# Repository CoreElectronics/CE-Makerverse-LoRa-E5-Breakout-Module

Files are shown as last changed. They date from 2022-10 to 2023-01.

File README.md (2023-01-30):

# Makerverse™ LoRa-E5 Breakout

This is the repo for the [Makerverse™ LoRa-E5 Breakout](https://core-electronics.com.au/catalog/product/view/sku/CE09196).

## License
This project is open source - please review the LICENSE.md file for further licensing information.

If you have any technical questions, or concerns about licensing, please contact technical support on the [Core Electronics forums](https://forum.core-electronics.com.au/).

## Attribution
The hardware design of this module is influenced by the [Wio-E5 mini](https://wiki.seeedstudio.com/LoRa_E5_mini/).

*\"Makerverse\" and the Makerverse logo are trademarks of Core Electronics Pty Ltd.*

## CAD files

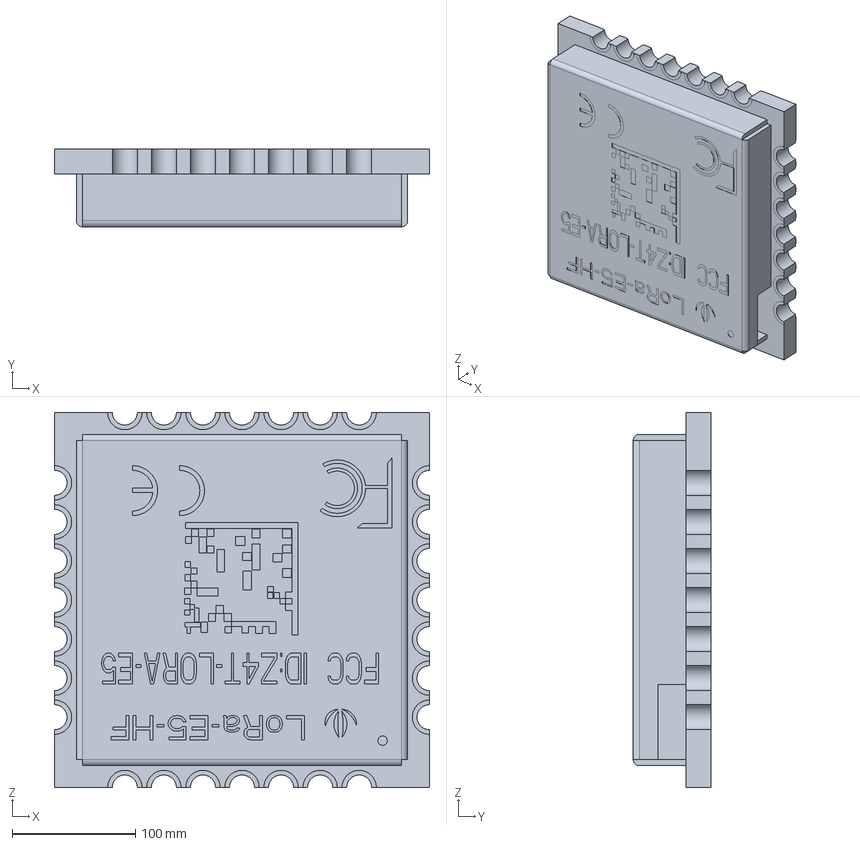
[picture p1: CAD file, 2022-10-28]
CAD/LoRa-E5-HF_3D_File.stp
304.8 x 63.8 x 304.8 mm

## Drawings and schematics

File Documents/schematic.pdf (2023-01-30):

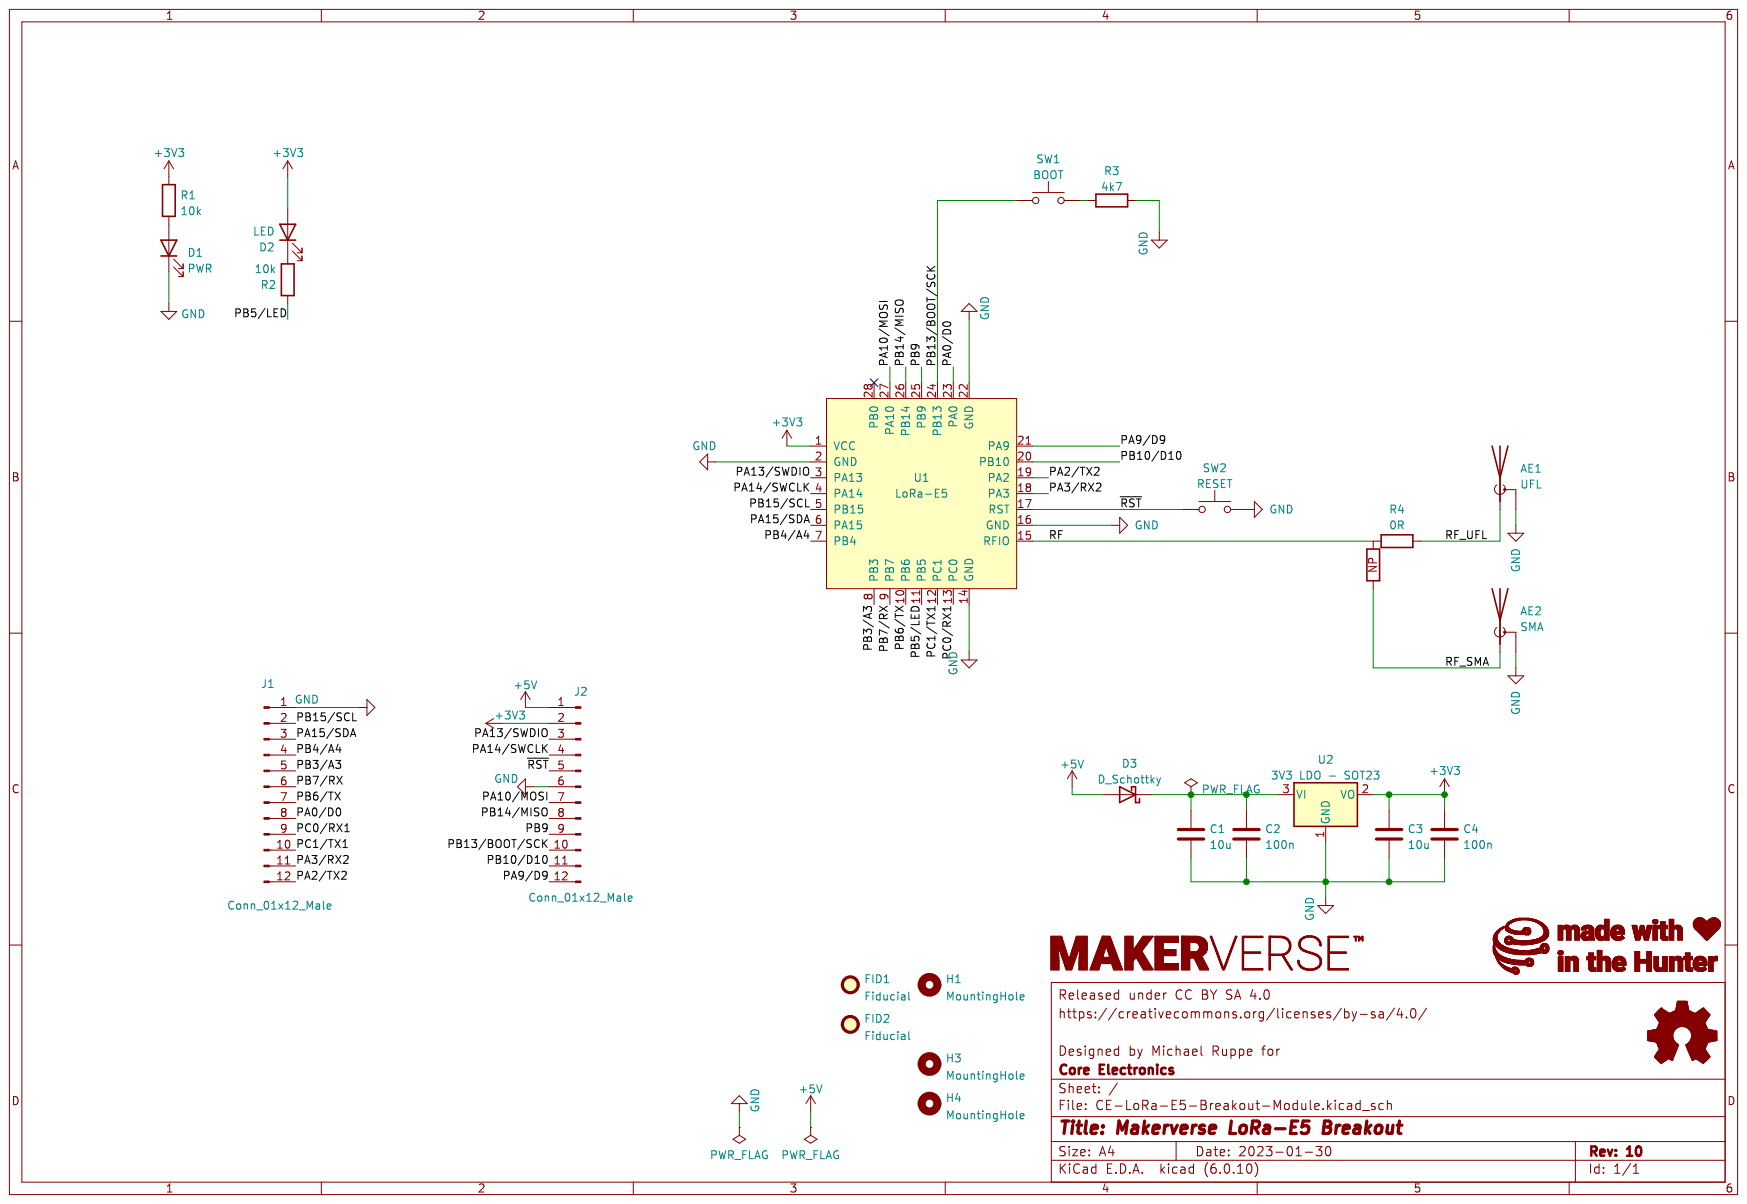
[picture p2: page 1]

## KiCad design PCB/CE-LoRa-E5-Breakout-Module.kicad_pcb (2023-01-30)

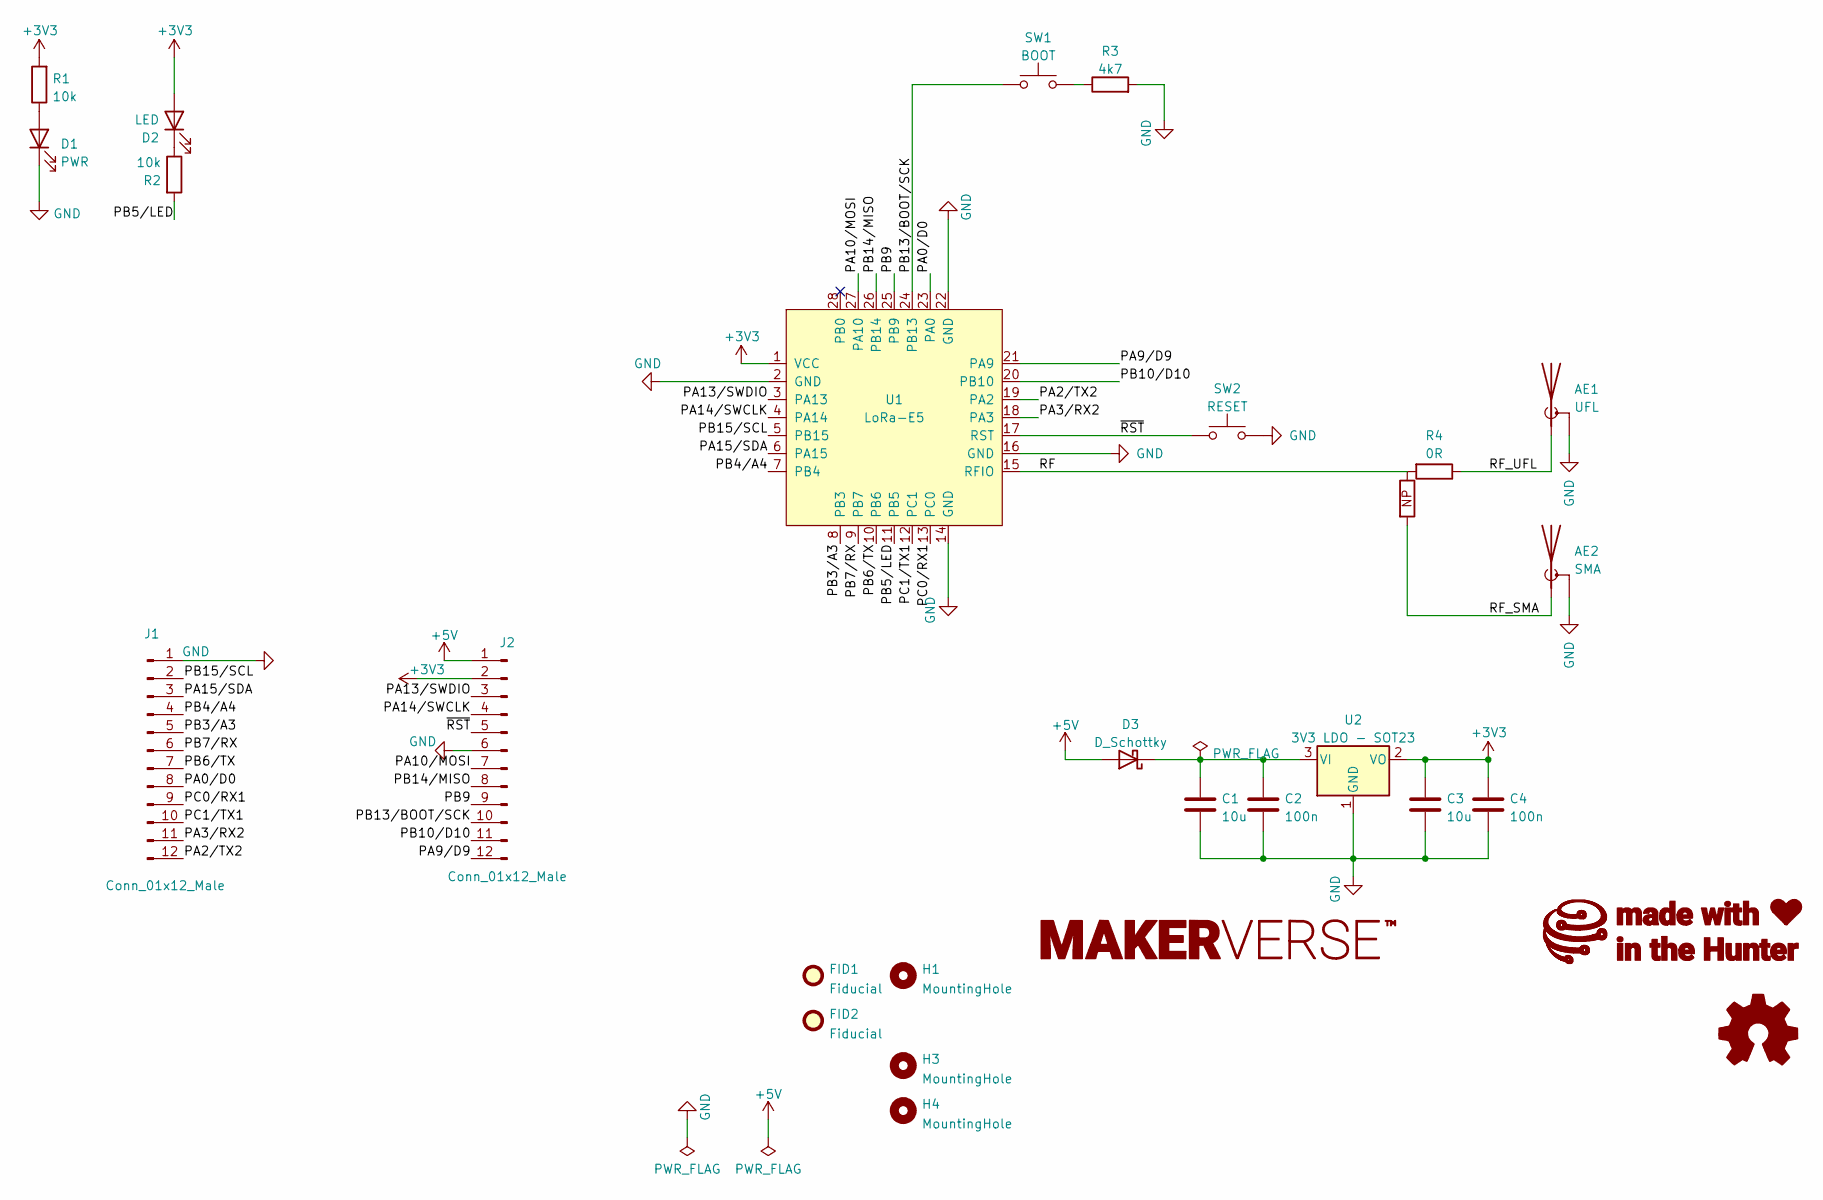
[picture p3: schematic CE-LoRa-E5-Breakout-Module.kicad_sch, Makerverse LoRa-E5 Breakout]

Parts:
AE1: UFL; U.FL_Hirose_U.FL-R-SMT-1_Vertical
AE2: SMA; Conn_RF_SMA_EdgeMount
C1, C3: 10u; C_0603_1608Metric
C2, C4: 100n; C_0402_1005Metric
D1: PWR; LED_0603_1608Metric
D2: LED; LED_0603_1608Metric
D3: D_Schottky; D_SMA
FID1, FID2: Fiducial; Fiducial_1mm_Mask2mm
G1: LOGO_Makerverse; makerverse_logo_short_14.0x2.4mm
G2: LOGO_CoreElectronics_made-with-love; makerverse_logo_35.8x4.2mm
H1, H3, H4: MountingHole; MountingHole_3.2mm_M3
J1, J2: Conn_01x12_Male; PinHeader_1x12_P2.54mm_Vertical
LOGO1: Logo_Open_Hardware_Small; oshw_3.9x3.5mm
R1, R2: 10k; R_0402_1005Metric
R3: 4k7; R_0402_1005Metric
R4: 0R; Jumper_Resistor_SPDT_0603_1608Metric
SW1: BOOT; SW_SPST_TL3342
SW2: RESET; SW_SPST_TL3342
U1: LoRa-E5
U2: 3V3 LDO - SOT23; SOT-23

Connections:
+3V3: C3.1, C4.1, D2.2 (A), J2.2, R1.2, U1.1 (VCC), U2.2 (VO)
+5V: D3.2 (A), J2.1
/PA0/D0: J1.8, U1.23 (PA0)
/PA2/TX2: J1.12, U1.19 (PA2)
/PA3/RX2: J1.11, U1.18 (PA3)
/PA9/D9: J2.12, U1.21 (PA9)
/PA10/MOSI: J2.7, U1.27 (PA10)
/PA13/SWDIO: J2.3, U1.3 (PA13)
/PA14/SWCLK: J2.4, U1.4 (PA14)
/PA15/SDA: J1.3, U1.6 (PA15)
/PB3/A3: J1.5, U1.8 (PB3)
/PB4/A4: J1.4, U1.7 (PB4)
/PB5/LED: R2.2, U1.11 (PB5)
/PB6/TX: J1.7, U1.10 (PB6)
/PB7/RX: J1.6, U1.9 (PB7)
/PB9: J2.9, U1.25 (PB9)
/PB10/D10: J2.11, U1.20 (PB10)
/PB13/BOOT/SCK: J2.10, SW1.1, U1.24 (PB13~)
/PB14/MISO: J2.8, U1.26 (PB14)
/PB15/SCL: J1.2, U1.5 (PB15)
/PC0/RX1: J1.9, U1.13 (PC0)
/PC1/TX1: J1.10, U1.12 (PC1)
/RF: R4.2, U1.15 (RFIO)
/RF_SMA: AE2.1 (A), R4.3
/RF_UFL: AE1.1 (A), R4.1
/~RST: J2.5, SW2.1, U1.17 (RST)
GND: AE1.2 (Shield), AE2.2 (Shield), C1.2, C2.2, C3.2, C4.2, D1.1 (K), J1.1, J2.6, R3.2, SW2.2, U1.2 (GND), U1.14 (GND), U1.16 (GND), U1.22 (GND), U2.1 (GND)
unnamed: C1.1, C2.1, D3.1 (K), U2.3 (VI)
unnamed: D1.2 (A), R1.1
unnamed: D2.1 (K), R2.1
unnamed: R3.1, SW1.2

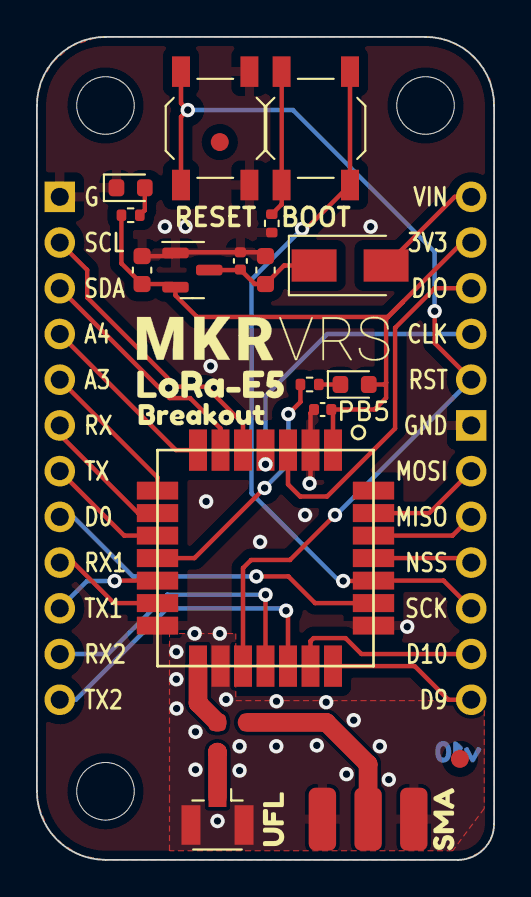
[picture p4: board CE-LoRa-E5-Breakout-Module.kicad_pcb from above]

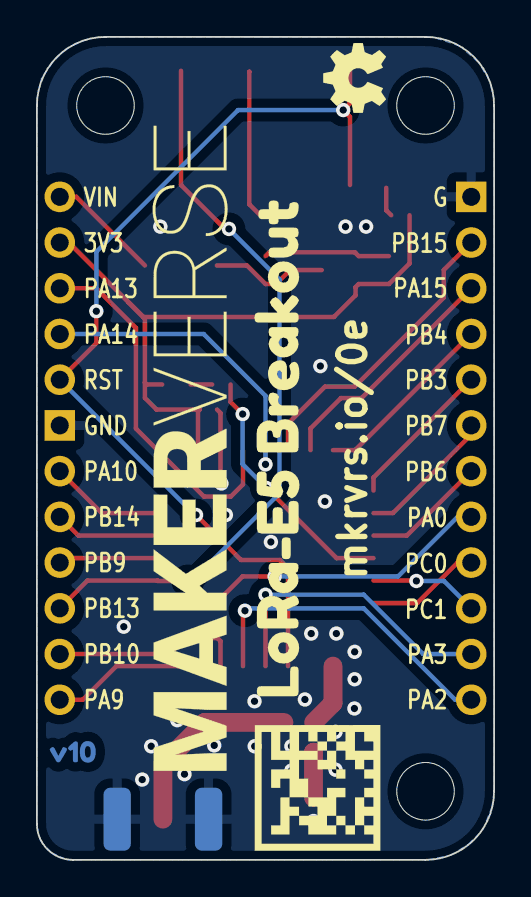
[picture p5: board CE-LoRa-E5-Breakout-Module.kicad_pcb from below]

Board: 2 copper layers, 25.4 x 45.7 mm, 33 parts (6 on the bottom side), 31 nets.

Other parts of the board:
kibuzzard-63AE194F: G***; kibuzzard-63AE194F
kibuzzard-635A0587: G***; kibuzzard-635A0587
kibuzzard-635B4E71: G***; kibuzzard-635B4E71
kibuzzard-635B4E81: G***; kibuzzard-635B4E81
kibuzzard-639FDA33: G***; kibuzzard-639FDA33
kibuzzard-639FDA51: G***; kibuzzard-639FDA51

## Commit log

2022-10-28 v0 initial commit
    [CE-LoRa-E5-Breakout-Module-B_Cu.gbl, CE-LoRa-E5-Breakout-Module-B_Mask.gbs, CE-LoRa-E5-Breakout-Module-B_Paste.gbp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]
2022-12-19 v02 prototype with SMA connector option
    [CE-LoRa-E5-Breakout-Module.kicad_pcb, CE-LoRa-E5-Breakout-Module.kicad_sch]

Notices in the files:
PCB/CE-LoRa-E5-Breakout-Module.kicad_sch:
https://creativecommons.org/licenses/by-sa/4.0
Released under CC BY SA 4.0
